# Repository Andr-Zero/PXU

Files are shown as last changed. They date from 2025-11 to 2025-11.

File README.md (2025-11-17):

# PXU - Replacement Power Supply for the Orignial Xbox!

## 🛑 VERY IMPORTANT SAFETY DISCLAIMER 🛑
This project involves working with and replacing a power supply unit that was originally designed to handle mains voltage. The original OEM power supply can retain a lethal electrical charge long after it has been unplugged. Proceed with extreme caution.

 **HIGH VOLTAGE RISK**: You are solely responsible for your safety. Improper handling of electronics can lead to serious injury, death, or fire. If you are not experienced and confident in working with electronics, do not attempt to install this hardware.

**USE AT YOUR OWN RISK**: This is a hobbyist project provided "as is" without warranties of any kind. The author, Andr0, is not responsible for any damage to your console, other property, or any personal injury that may occur from the use or misuse of this hardware.
___
## Features
-   ✨Support 1.0 through 1.6 revisions consoles! ✨  
    *1.0/1.1 requires the proper 12-pin connector.  
    *Switching between 1.0-1.4 and 1.6s requires changing several zero ohm resistors, documented on bottom of the PCB.
-   Accepts any DC input from 16-20V, 100W+ (Including 100W USB-C PD chargers).
-   Features user-replaceable input modules.
-   Designed as a direct swap with the OEM power supply, using the same mounting points.

## Installation
**Warning:** The OEM power supply can be dangerous even after being unplugged for long periods. Proceed with caution!

1.  **Make sure the AC power cord is unplugged from the wall!** Then, press the Xbox's power button a few times to help discharge any residual power.
2.  Open the console and remove the hard drive tray.
3.  Unplug the cable connecting the OEM power supply to the mainboard.
4.  Remove the two screws holding the power supply down. Slide it toward the front of the console just enough to disengage it from the shell's retaining clips.
5.  The power supply should now lift out. You may need to angle it to get it out of the shell.
6.  Installation is the reverse of this process.

## FAQ
**Will my "******"  work as a power source?** I cannot test every power source available. I have personally tested an MSI laptop charger (180W) and an Anker 100W USB-C charger. Similar adapters that meet the specification of 16-20V and can deliver 100W or more should work.

**Can you add feature "X"?** The goal of the main PXU board is to be a drop-in replacement that powers the console just like the OEM supply. Additional features can and should be added as daughterboards using the provided mount points.

**I dont see the USB-C Board Here.** That's in another repo: https://github.com/Andr-Zero/PXU-C-PIM

## License

This project is open-source hardware, licensed under the **CERN-OHL-S v2** (CERN Open Hardware Licence - Strongly Reciprocal).

**Copyright © 2025 Andr0**

You are free to:

-   **Use and reproduce** this design for any purpose.
-   **Modify** the design to fit your needs.  
-   **Distribute** the original design or your modifications.

In return, you must:

-   **Give credit**
-   **Share your changes** under the same CERN-OHL-S v2 license.
-  **Keep all copyright and license notices intact.** As a condition of the license's attribution requirement, all original markings on the PCB silkscreen must be retained. This includes the copyright notice, the PXU and Team Resurgent logos, and any project URLs present in the original design files. These should not be removed or altered.

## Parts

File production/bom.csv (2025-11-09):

Designator | Footprint | Quantity | Value | LCSC Part #
_6, _5, _4, _3, _2, |  | 6
12V, 5V, GND | TestPoint_THTPad_D4.0mm_Drill2.0mm | 3 | TestPoint
C1, C11, C17, C44 | 0603 | 4 | 1uF 16V
C10 | 0805 | 1 | 220nF 25V
C12, C33, C34, C35, C41, C42, C65 | 0603 | 7 | 100nF 10V
C13 | 0603 | 1 | 12pF 25V
C14, C45, C46, C47, C55 | 0805 | 5 | 22uF 25V
C15, C28, C31, C32, C5, C59, C64 | 0603 | 7 | 100nF 50V
C16, C18, C2, C20, C3, C6, C9 | 1210 | 7 | 47uF 25V
C19, C4 | 0603 | 2 | 4.7uF 25V
C21, C22, C36, C38, C40, C48, C69, C7, C70 | 0603 | 9 | 1uF 10V
C23 | CP_Radial_D10.0mm_P5.00mm | 1 | 1500uF 6.3V
C24 | 0603 | 1 | 1uF 35V
C25 | 0603 | 1 | 2.2uF 6.3V
C26, C43, C49, C50, C51, C52, C53, C54, C67, C68 | 1206 | 10 | 100uF 10V
C27, C8 | CP_Radial_D10.0mm_P5.00mm | 2 | 2200uF 16V
C29 | 0603 | 1 | 1nF 50V
C30 | 0603 | 1 | 180pF
C37, C63 | 0805 | 2 | 10uF 10V
C39 | 0603 | 1 | 100pF
C56 | 0603 | 1 | 1uF 6.3V
C57, C58 | 1210 | 2 | 22uF 35V
C60, C61 | 1206 | 2 | 100nF 50V
C62 | CP_Radial_D10.0mm_P5.00mm | 1 | 680uF 35V
C66 | 0603 | 1 | 10uF 16V
IC1 | SON50P500X600X150-23N-D | 1 | TPS53319DQPT
IC2 | SON50P500X600X150-23N-D | 1 | TPS53318DQPT
J1 | Molex_Mini-Fit_Jr_5566-20A_2x10_P4.20mm_Vertical | 1 | 39-38-1203
J2 | CONN_171826-4_TYCO_TYC | 1 | 171826-4
L1 | L_10.4x10.4_H4.8 | 1 | XAL1010-222MED
L2 | L_6.3x6.3_H3 | 1 | XAL6060-103MEB
L3 | L_6.3x6.3_H3 | 1 | XAL6060-472MEC
R1 | 0603 | 1 | 150kΩ
R10 | 1206 | 1 | 0Ω
R11, R2, R26, R32, R33, R4, R6 | 0603 | 7 | 0Ω
R12, R13, R14, R16, R20, R3, R7 | 0603 | 7 | 105kΩ
R15 | 0603 | 1 | 9.53kΩ
R17, R23 | 1206 | 2 | 1MΩ
R18 | 0603 | 1 | 80.6kΩ
R19, R5 | 0603 | 2 | 475kΩ
R21, R8 | 0603 | 2 | 10kΩ
R22 | 0603 | 1 | 44.2kΩ
R24 | 0603 | 1 | 105k Ω
R25 | 0603 | 1 | 33 Ω
R27 | 1206 | 1 | 3Ω
R28 | 0805 | 1 | 1.87kΩ
R29 | 0805 | 1 | 3Ω
R31 | 0603 | 1 | 55kΩ
R34 | 0603 | 1 | 22Ω
R37 | 0603 | 1 | 100Ω
R9 | 0603 | 1 | 71.5kΩ
U1 | D14 | 1 | SN74LVC08ADR
U2 | Texas_HSOP-8-1EP_3.9x4.9mm_P1.27mm_ThermalVias | 1 | LMR33640ADDAR
U3 | CSD25402Q3A | 1 | CSD25402Q3A
U4 | SO-8EP_DIO | 1 | AP7375Q-33SP-13
U5 | SOT-23-5 | 1 | UCC27517A
U6 | SOT-23-6_Handsoldering | 1 | SN74LVC2G17DBVR

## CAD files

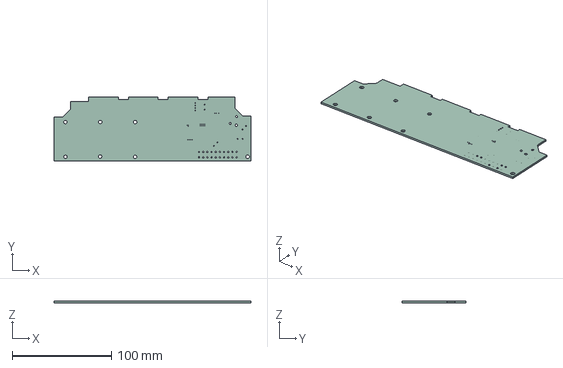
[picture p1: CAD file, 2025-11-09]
KiCad/PXU.step
198.0 x 64.5 x 1.51 mm

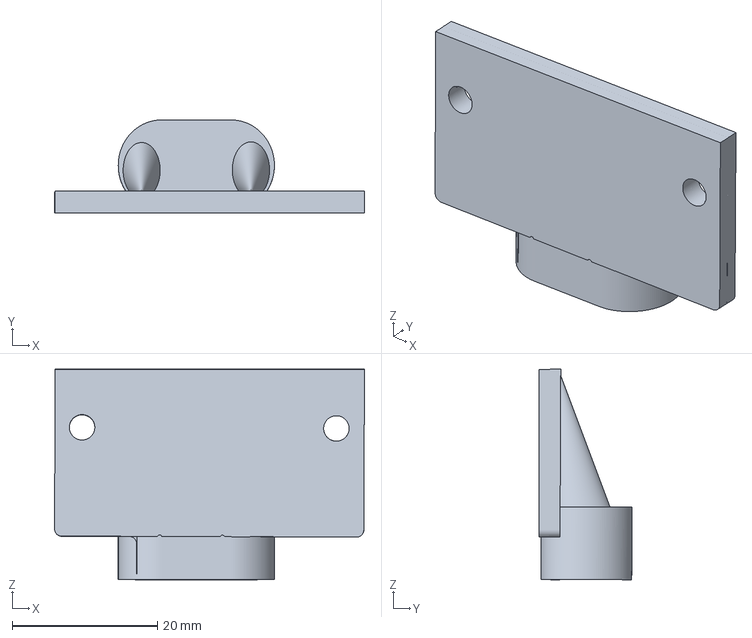
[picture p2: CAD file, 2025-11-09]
PXU Plug Blank.3mf
42.7 x 12.8 x 29.0 mm

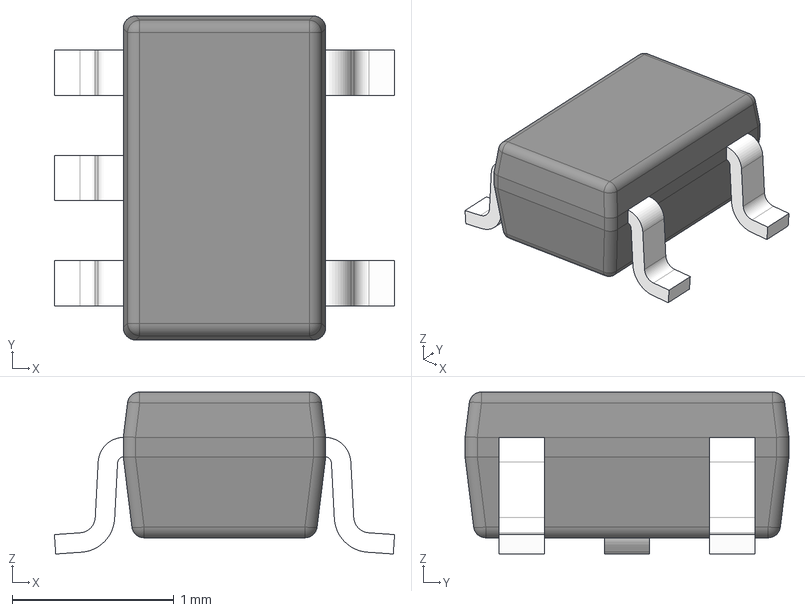
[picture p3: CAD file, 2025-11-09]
KiCad/Imports/DCK0005A.stp
2.10 x 2.00 x 1.00 mm
BODY-SOT
LEAD-SOT x 5
PIN1-ID

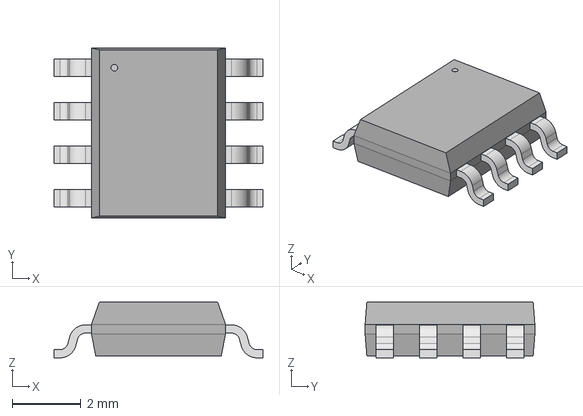
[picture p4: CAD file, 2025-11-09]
KiCad/Imports/SO-8EP_DIO.step
6.10 x 4.95 x 1.63 mm

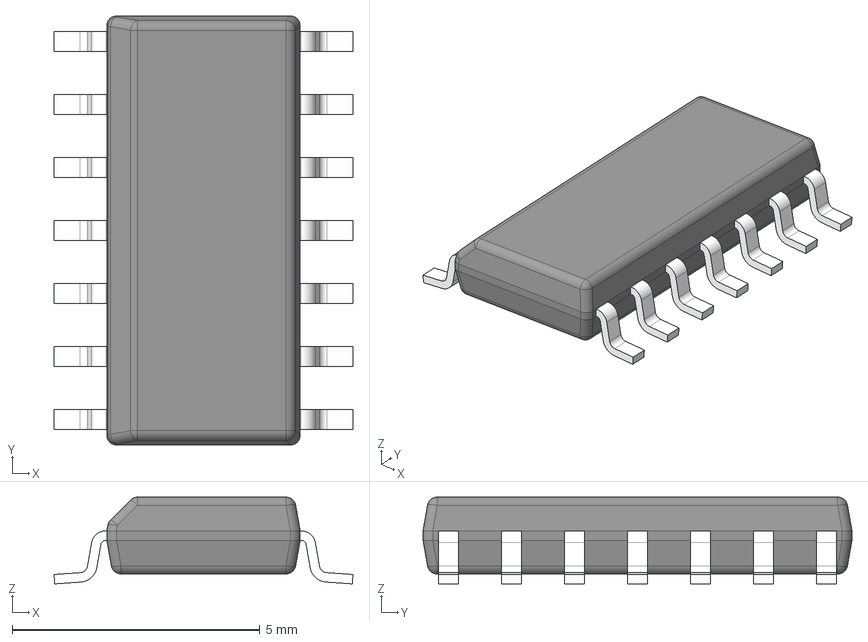
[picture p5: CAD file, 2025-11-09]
KiCad/Imports/D0014A.stp
6.03 x 8.65 x 1.75 mm
BODY-SO
LEAD-SO x 14
PIN1-ID

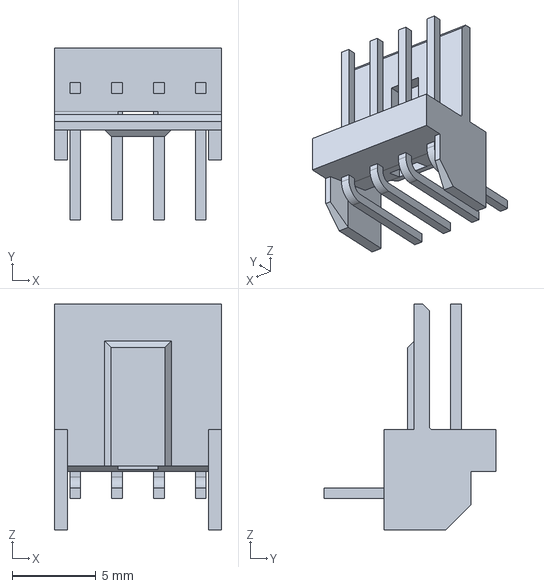
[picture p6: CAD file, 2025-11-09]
KiCad/Imports/CONN_171826-4.stp
10.0 x 10.3 x 13.5 mm

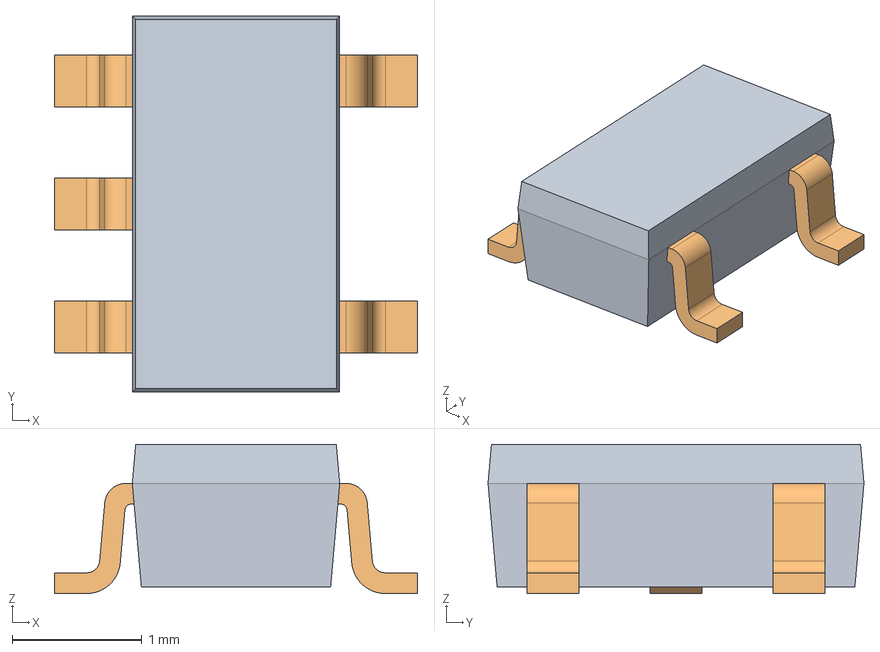
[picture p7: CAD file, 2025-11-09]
KiCad/Imports/SMV_z90.stp
2.80 x 2.90 x 1.15 mm

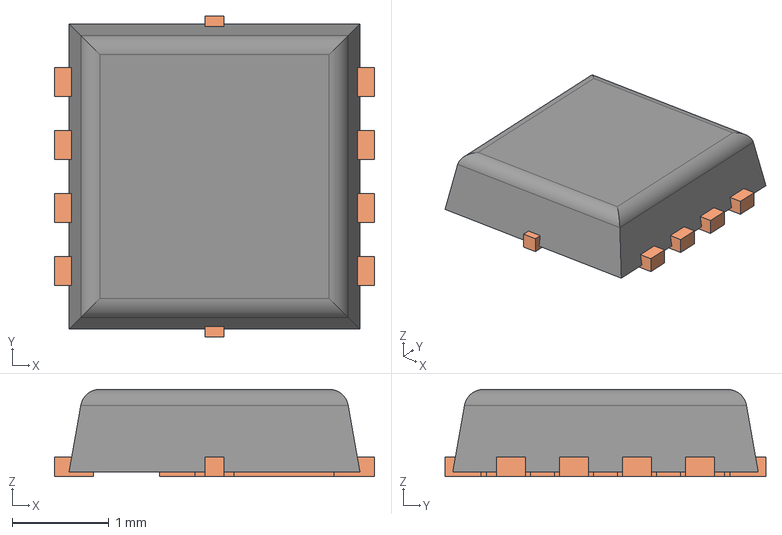
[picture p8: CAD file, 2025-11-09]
KiCad/Imports/CSD25402Q3A.stp
3.30 x 3.31 x 0.9 mm
FRAME

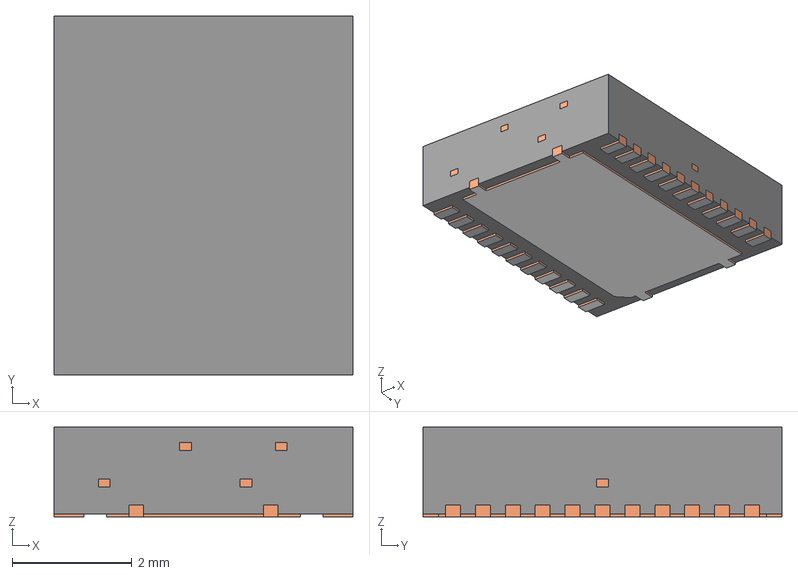
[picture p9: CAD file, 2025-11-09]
KiCad/Imports/TPS53319DQPT.stp
5.00 x 6.00 x 1.50 mm
BODY-SON
FRAME-DQP0022A
PIN1-ID
CLIP1-LSON
CLIP2-LSON

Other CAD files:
KiCad/Imports/DCK0006A.stp
KiCad/Imports/SO-8EP_DIO.stl

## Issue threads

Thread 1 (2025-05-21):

Open Source

harrypm, 2025-05-21:
Hello your project is getting some SEO score attention with prototypes in the wild, so I figured I would come in here and say this is neat, I've got an Xbox I'm going to be refitting soon so good timing I hope.

What I'd like to mention is if you're actually making something for the open source community, please start from the ground up as open source so you're design revisioning can be peer reviewed by fellow engineers, If not improved upon with orientations for cost-effectiveness and long endurance designs.

Would be nice to know if there's some sort of timeline here, because it is awkward making these sort of pokes.

Overall love this project hope this gets mass adoption in the modding community.

eimparas, 2025-05-25:
came here from the MatKC [video](https://www.youtube.com/watch?v=xhCOKw-ICsg) and i thought that i could look at the desing since it peaked my interest

Andr-Zero, 2025-08-08:
Thanks for the interest! I will be publishing everything and releasing the source for everything once I feel the project is ready or as complete as I can make it.

harrypm, 2025-08-08:
> Thanks for the interest! I will be publishing everything and releasing the source for everything once I feel the project is ready or as complete as I can make it.

That means this issue is still valid and standing, that's not how issue tickets work on GitHub.

Andr-Zero, 2025-08-09:
From my understanding of how issues work on github, it's really up to the owner on how they work.

I am going to reopen, and pin,  to serve as a FAQ and allow open dialog.

In regards to peer review. I do agree that to a degree. For me to really understand HOW things work, I still need to tinker and learn. I REALLY hope to have something released soon-ish. I have one specific issue I'm working on, once I have that done and test boards done. I REALLY hope that's it. It's the last thing on my list. After that it's go time! :)

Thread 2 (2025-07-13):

Bas intermittent boot looping 1.0

splitbarrel2, 2025-07-13:
I’m on a 1.0v console and have already ran all 5 jumpers for the trace rot on the power button circuits and recapped all cpu and power related caps. My issue is that many times turning the console on it will try to boot but the moment the fans and HDD get power it turns off (no lights on the front). Unplugging the console from the wall sometimes helps other times it does not. Sometimes unplugging the type c charger from the wall fixes it but not always. Lately it’s been getting really bad. I frequently open my console up and take out the motherboard. This last time I noticed some strain on the top two white and blue wires that are for the power data transfer back to the pxu. They almost looked severed so I cut them past the strain point and resoldered. That seemed to help for a little bit but didn’t fix it either. I really like having the usbc charging but I’m about at my wits end trying to figure out why I have to play with it like this someone please tell me what I’m doing wrong or if those wires are just prone to internal breaking and should be replaced with thicker gage I’m so lost.

Andr-Zero, 2025-07-13:
1.0s have a noticeable inrush compared the later revisions, finding very few adapters are not particular happy with them. For example, the Anker adapter I've been using does not like to reboot the console after running for more than 15 minutes. What AC adapter are you using? Do you have another adapter to test with? Just only to verify that is not problem. Also when it fails to boot, does the LEDs on the USB board change?

The length of the Blue\White cables indeed should be longer. The next order of supplies will about 3-4cm longer, maybe more. likely to do the same with the two black and orange wire, not sure yet. Have not heard anyone say anything about them breaking internally.

splitbarrel2, 2025-07-14:
Thank you so much for your quick reply! I've spent the last day making absolutely sure that it was not something to do with the wiring for the trace rot or any other weird wiring and doing some trouble shooting! The adapter that I am using is a "j5create 108W USB-C Super Charger". It states that it can due 100w over the type-c (20v 5a) so long as nothing else is also plugged into it. I don't have another AC adapter at the moment capable of the 100w but I will order another one ASAP and update you when I get it to see if it is just that. When it fails to boot the green light in the middle (Labeled D2) stays on and does not blink or change color.

I'd like to clarify its not exactly boot looping. To be more specific pressing the power button causes the fans to spin for less than 1 second, the HDD to make a noise, the controller lights to flash and then it kills itself. Sometimes when it fails it fails HARD barely spins a fan at all and the flash for the controller would be very fast. Other times it would spin them much harder almost a full second or so. The controller would even light up for second too. Like it was about to power on but just couldn't. Holding the power button causes the system to repeat the fail until unpressed however it did launch during the fail cycle a couple of times. Pressing / Holding the eject button gives the same thing. It seems like the longer i use the adapter the more it likes to act up. Towards the first 5 minutes or so it works very well the failure rate is super low but the more time plugged in the more likely it is to fail booting. After about 20 minutes of being plugged in I'm lucky if i can get it turned back on at all. The only thing that works without unplugging something is waiting with the console powered off for 30-60 seconds then pressing the power button.

Also I've been noticing that I've been getting some screen flashing while playing games that I do not get with the OEM power supply. It's oddly intermittent sometimes it happens 10 times in a minute and sometimes once in 2 or 3 minutes and nothing in particular seems to cause it or make it worse. The screen flashing sometimes appears as distortion to the image that lasts for no more than a frame or two and other times it's a total black flash lasting for the same amount of time. I've tried to press a button at the same time of the flashing to confirm its not just a visual effect and it does not appear to take the command if pressed at ruffly the same time as a flash.

As for the blue and white wires it would be nice to have them a bit longer but I just wanted to make sure that the stress spot I put on them by accidently forcing the HDD tray down on the wires wasn't causing a break or bad connection.

splitbarrel2, 2025-07-14:
I was able to obtain another usb-c charger. An anker 140w, 4-port, PD 3.1 its even got a small screen on it to show which port is using how much wattage. I've been playing with it for a little bit now and it appears to do the same thing with about the same frequency. If this is due to the inrushing issues would it be possible to easily add an inrush current limiter to any part of the circuit without designing a new pcb just to see if it would be more stable?

Andr-Zero, 2025-07-14:
Before you order another AC adapter, the one you have *SHOULD* work just fine. Lets see if we can do some basic testing. Do you have a voltmeter? Are you willing to measure some voltages for me if you do?

I called it boot looping for lack of a better term, perhaps short cycling? What you're describing is indicative of the PwrGood signal not getting asserted properly.  Voltage rails must come to within 10% of it's target within the soft-start time, then this signal tells the console to start running. If it does not receive that signal within a set timeframe from letting go of the front buttons, the console stops trying to turn on.

Seen a couple reasons why this happens, most common issues I've found so far are; a short circuit, loose connection somewhere, unstable input, and failing\incorrect capacitors in the console. The "Sometimes works, sometimes doesn't" you describe does lead me to believe that it's something to do with the input side. The unplugging of the AC adapter reinforces this thought. If that is the AC adapter or the USB-C board, that is the question.

The screen flickering is a new one. That I would have to look into more.

I'm going to cut myself off here since I see you added another update as I was typing. Having tried another adapter, I'm wanting to swap the pxu and see if the problem continues. Can you contact me on my shop with the order number? I feel this is the best way to get to the quickest resolution.

Andr-Zero, 2025-08-08:
Just to close this up for anyone else following along. I ended exchanging the unit. The 3.3v LDO failed, swapping it caused it to work properly again.

Closed 2025-08-08.

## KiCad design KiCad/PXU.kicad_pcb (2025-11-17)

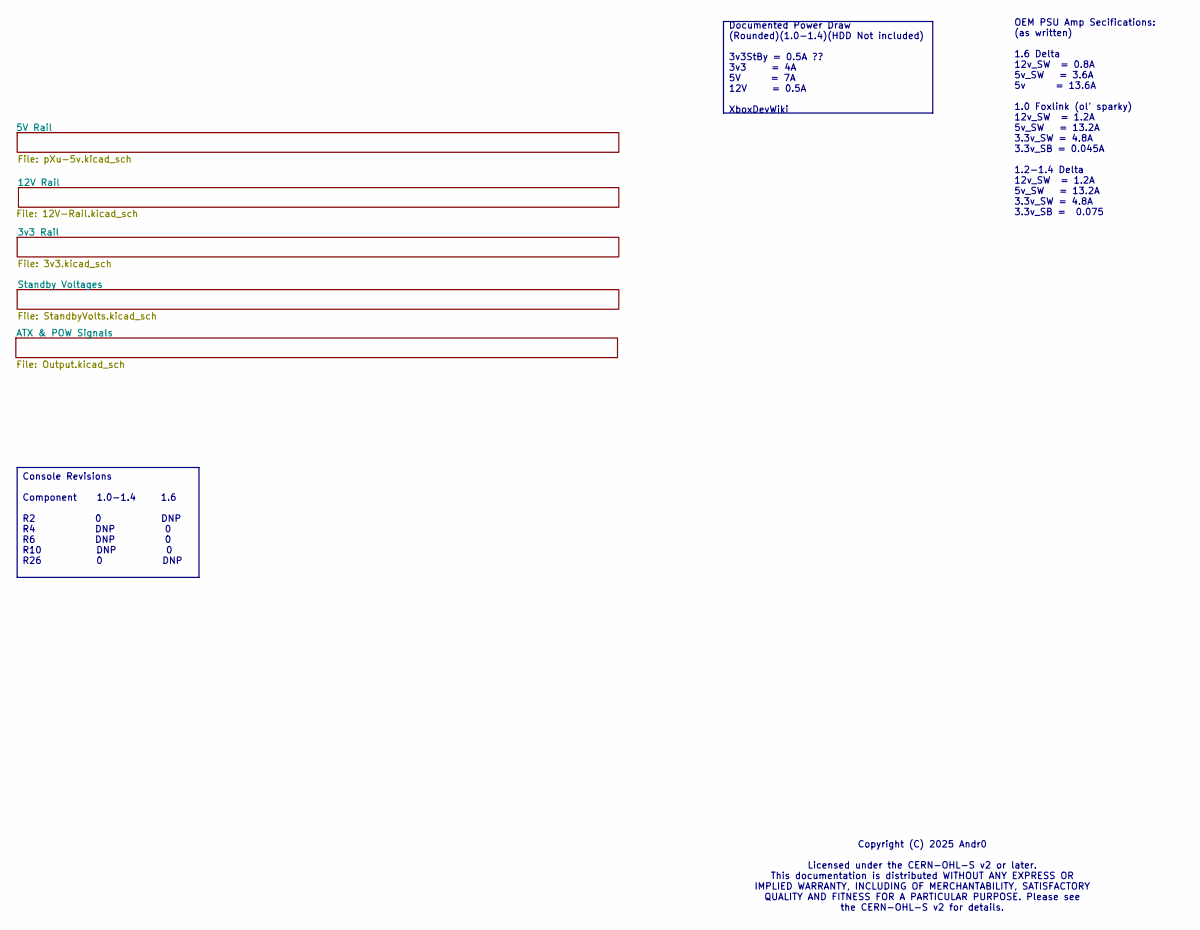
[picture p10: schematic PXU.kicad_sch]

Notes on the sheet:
OEM PSU Amp Secifications: (as written) 1.6 Delta 12v_SW = 0.8A 5v_SW = 3.6A 5v = 13.6A 1.0 Foxlink (ol' sparky) 12v_SW = 1.2A 5v_SW = 13.2A 3.3v_SW = 4.8A 3.3v_SB = 0.045A 1.2-1.4 Delta 12v_SW = 1.2A 5v_SW = 13.2A 3.3v_SW = 4.8A 3.3v_SB = 0.075
Copyright (C) 2025 Andr0 Licensed under the CERN-OHL-S v2 or later. This documentation is distributed WITHOUT ANY EXPRESS OR IMPLIED WARRANTY, INCLUDING OF MERCHANTABILITY, SATISFACTORY QUALITY AND FITNESS FOR A PARTICULAR PURPOSE. Please see the CERN-OHL-S v2 for details.
Console Revisions Component 1.0-1.4 1.6 R2 0 DNP R4 DNP 0 R6 DNP 0 R10 DNP 0 R26 0 DNP
Documented Power Draw (Rounded)(1.0-1.4)(HDD Not included) 3v3StBy = 0.5A ?? 3v3 = 4A 5V = 7A 12V = 0.5A XboxDevWiki

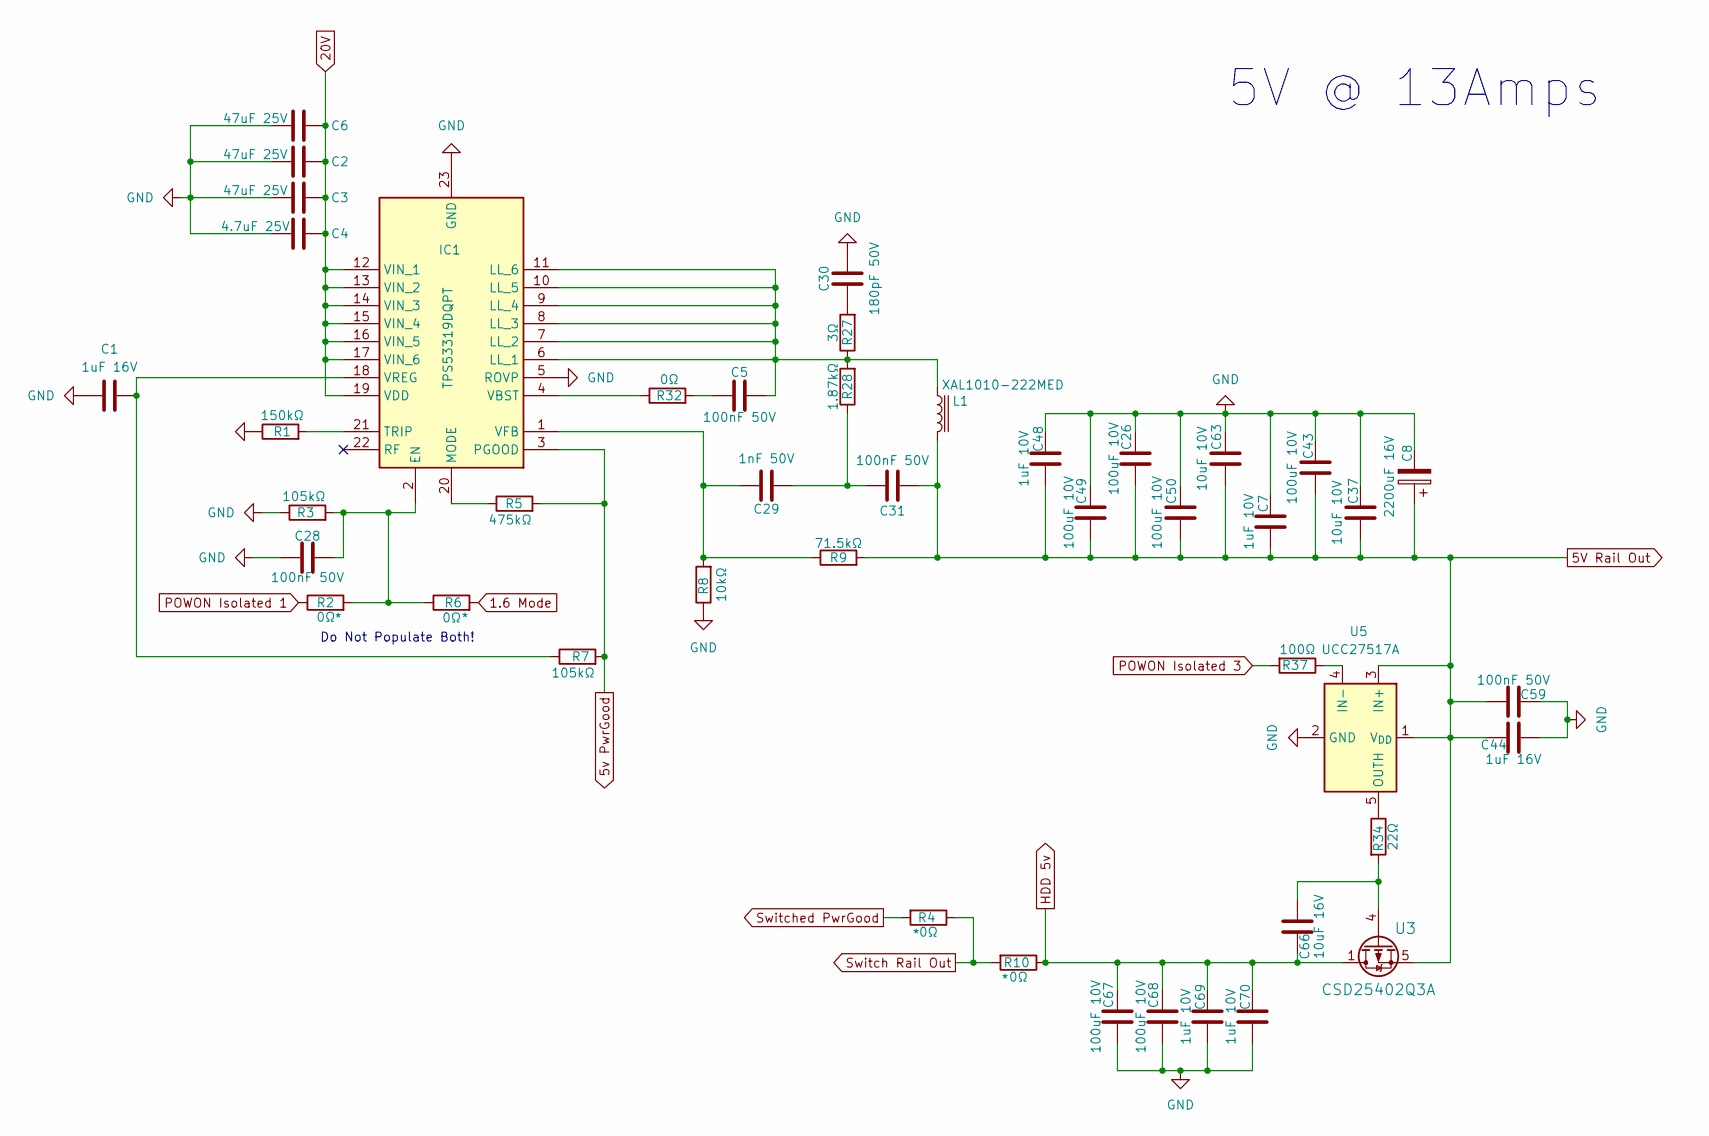
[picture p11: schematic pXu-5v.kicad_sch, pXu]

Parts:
C1, C44: 1uF 16V; C_0603_1608Metric_Pad1.08x0.95mm_HandSolder
C2, C3, C6: 47uF 25V; C_1210_3225Metric_Pad1.33x2.70mm_HandSolder
C4: 4.7uF 25V; C_0603_1608Metric_Pad1.08x0.95mm_HandSolder
C5, C28, C31, C59: 100nF 50V; C_0603_1608Metric_Pad1.08x0.95mm_HandSolder
C7, C48, C69, C70: 1uF 10V; C_0603_1608Metric_Pad1.08x0.95mm_HandSolder
C8: 2200uF 16V; CP_Radial_D10.0mm_P5.00mm
C26, C43, C49, C50, C67, C68: 100uF 10V; C_1206_3216Metric_Pad1.33x1.80mm_HandSolder
C29: 1nF 50V; C_0603_1608Metric_Pad1.08x0.95mm_HandSolder
C30: 180pF 50V; C_0603_1608Metric_Pad1.08x0.95mm_HandSolder
C37, C63: 10uF 10V; C_0805_2012Metric_Pad1.18x1.45mm_HandSolder
C66: 10uF 16V; C_0603_1608Metric_Pad1.08x0.95mm_HandSolder
IC1: TPS53319DQPT; SON50P500X600X150-23N-D; Mouser Part Number 595-TPS53319DQPT
L1: XAL1010-222MED; L_10.4x10.4_H4.8; Part# XAL1010-222MED
R1: 150kΩ; R_0603_1608Metric_Pad0.98x0.95mm_HandSolder
R2, R4, R6, R32: 0Ω; R_0603_1608Metric_Pad0.98x0.95mm_HandSolder
R3, R7: 105kΩ; R_0603_1608Metric_Pad0.98x0.95mm_HandSolder
R5: 475kΩ; R_0603_1608Metric_Pad0.98x0.95mm_HandSolder
R8: 10kΩ; R_0603_1608Metric_Pad0.98x0.95mm_HandSolder
R9: 71.5kΩ; R_0603_1608Metric_Pad0.98x0.95mm_HandSolder
R10: 0Ω; R_1206_3216Metric_Pad1.30x1.75mm_HandSolder
R27: 3Ω; R_1206_3216Metric_Pad1.30x1.75mm_HandSolder
R28: 1.87kΩ; R_0805_2012Metric_Pad1.20x1.40mm_HandSolder
R34: 22Ω; R_0603_1608Metric_Pad0.98x0.95mm_HandSolder
R37: 100Ω; R_0603_1608Metric_Pad0.98x0.95mm_HandSolder
U3: CSD25402Q3A; VSON-8_3.3x3.3mm_P0.65mm_NexFET
U5: UCC27517A; SOT-23-5

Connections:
1.6 Mode: R6.2; also elsewhere on the board
5V Rail Out: C7.2, C8.1, C26.2, C31.1, C37.2, C43.2, C44.1, C48.2, C49.2, C50.2, C59.2, C63.2, L1.2, R9.2, U3.5 (S), U5.1 (V_{DD}), U5.3 (IN+); also elsewhere on the board
5v PwrGood: IC1.3 (PGOOD), R5.2, R7.2; also elsewhere on the board
20V: C2.2, C3.2, C4.2, C6.2, IC1.12 (VIN_1), IC1.13 (VIN_2), IC1.14 (VIN_3), IC1.15 (VIN_4), IC1.16 (VIN_5), IC1.17 (VIN_6), IC1.19 (VDD); also elsewhere on the board
GND: C1.1, C2.1, C3.1, C4.1, C6.1, C7.1, C8.2, C26.1, C28.1, C30.2, C37.1, C43.1, C44.2, C48.1, C49.1, C50.1, C59.1, C63.1, C67.2, C68.2, C69.2, C70.2, IC1.5 (ROVP), IC1.23 (GND), R1.1, R3.1, R8.1, U5.2 (GND); also elsewhere on the board
HDD 5v: C66.1, C67.1, C68.1, C69.1, C70.1, R10.1, U3.1 (D), U3.2 (D), U3.3 (D); also elsewhere on the board
unnamed: C5.2, R32.2
unnamed: C29.1, C31.2, R28.1
unnamed: C30.1, R27.2
unnamed: C28.2, IC1.2 (EN), R2.2, R3.2, R6.1
unnamed: C5.1, IC1.6 (LL_1), IC1.7 (LL_2), IC1.8 (LL_3), IC1.9 (LL_4), IC1.10 (LL_5), IC1.11 (LL_6), L1.1, R27.1, R28.2
unnamed: IC1.20 (MODE), R5.1
unnamed: IC1.21 (TRIP), R1.2
unnamed: IC1.4 (VBST), R32.1
unnamed: C29.2, IC1.1 (VFB), R8.2, R9.1
unnamed: C1.2, IC1.18 (VREG), R7.1
unnamed: C66.2, R34.2, U3.4 (G)
unnamed: R37.1, U5.4 (IN-)
unnamed: R34.1, U5.5 (OUTH)
POWON Isolated 1: R2.1; also elsewhere on the board
POWON Isolated 3: R37.2; also elsewhere on the board
Switch Rail Out: R4.1, R10.2; also elsewhere on the board
Switched PwrGood: R4.2; also elsewhere on the board

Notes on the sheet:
Do Not Populate Both!
5V @ 13Amps

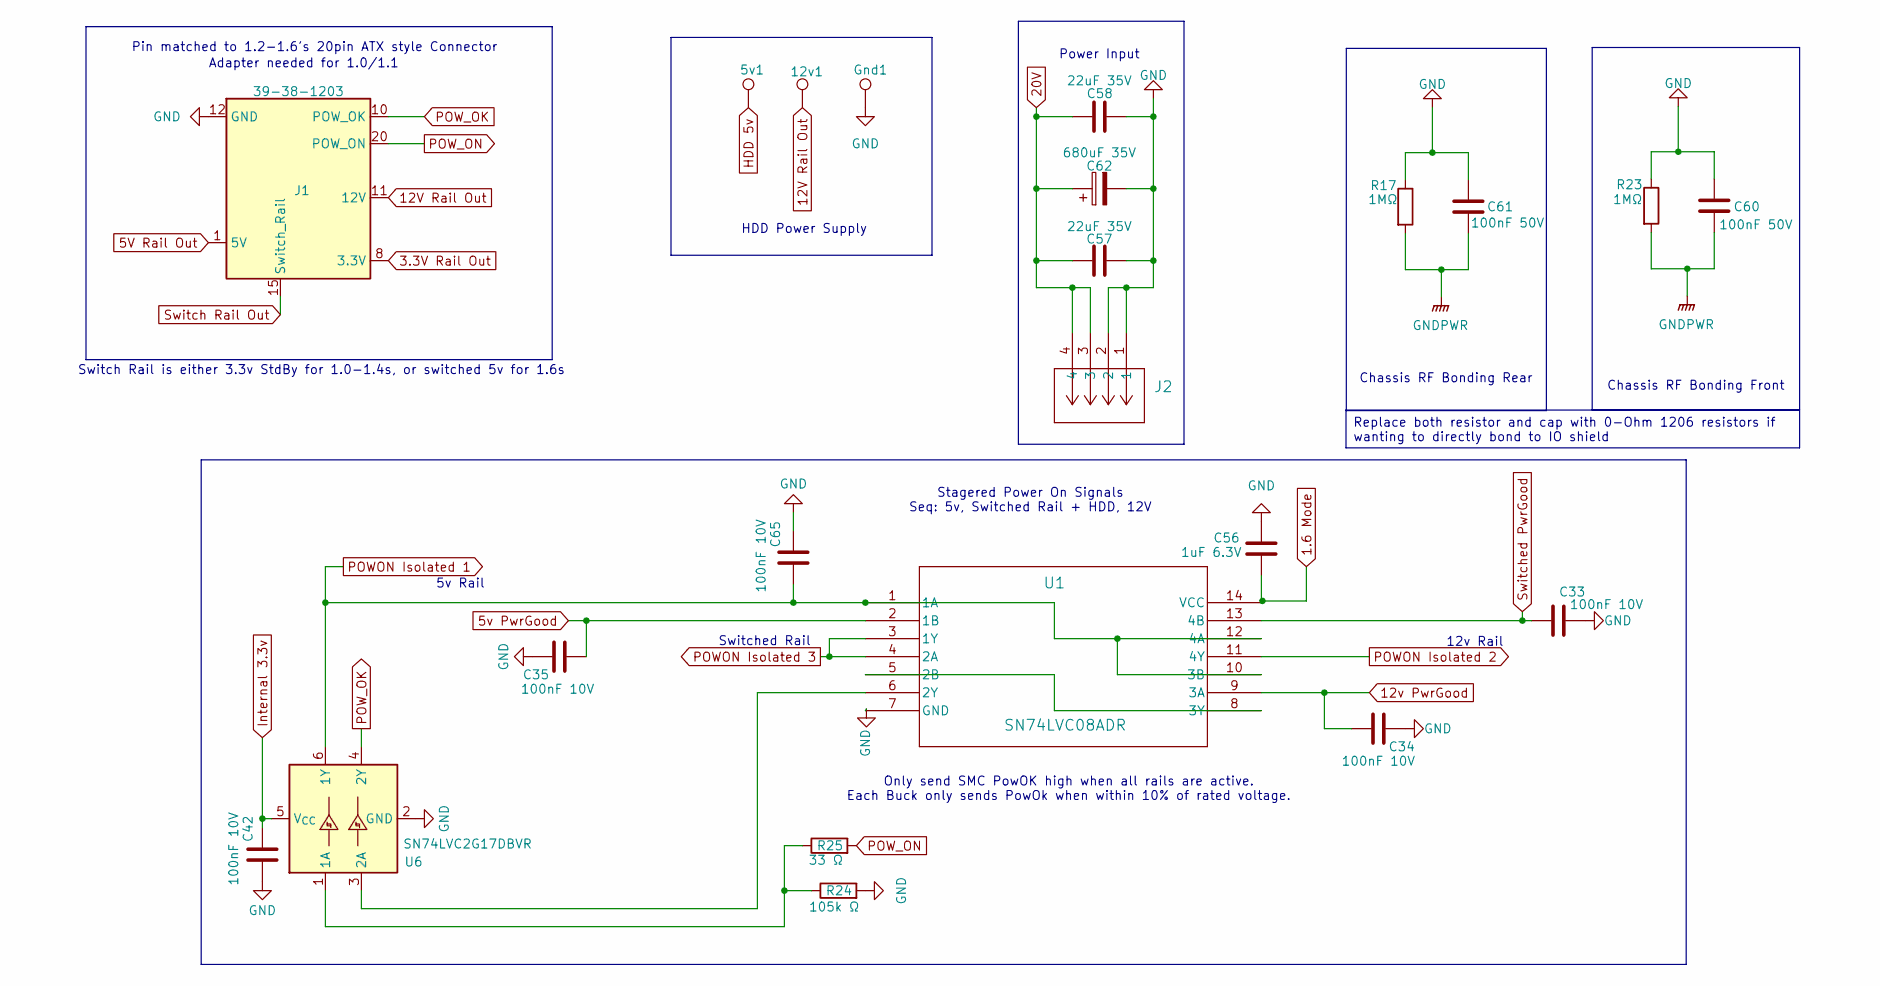
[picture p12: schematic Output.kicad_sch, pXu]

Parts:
5v1, 12v1: TestPoint; TestPoint_THTPad_D4.0mm_Drill2.0mm
C33, C34, C35, C42, C65: 100nF 10V; C_0603_1608Metric_Pad1.08x0.95mm_HandSolder
C56: 1uF 6.3V; C_0603_1608Metric_Pad1.08x0.95mm_HandSolder
C57, C58: 22uF 35V; C_1210_3225Metric_Pad1.33x2.70mm_HandSolder
C60, C61: 100nF 50V; C_1206_3216Metric_Pad1.33x1.80mm_HandSolder
C62: 680uF 35V; CP_Radial_D10.0mm_P5.00mm
Gnd1: TestPoint; TestPoint_THTPad_D4.0mm_Drill2.0mm
J1: 39-38-1203; Molex_Mini-Fit_Jr_5566-20A_2x10_P4.20mm_Vertical
J2: 171826-4; CONN_171826-4_TYCO_TYC
R17, R23: 1MΩ; R_1206_3216Metric_Pad1.30x1.75mm_HandSolder
R24: 105k Ω; R_0603_1608Metric_Pad0.98x0.95mm_HandSolder
R25: 33 Ω; R_0603_1608Metric_Pad0.98x0.95mm_HandSolder
U1: SN74LVC08ADR; D14
U6: SN74LVC2G17DBVR; SOT-23-6_Handsoldering

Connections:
1.6 Mode: C42.2, C56.2, U1.14 (VCC), U6.5 (V_{CC}); also elsewhere on the board
3.3V Rail Out: J1.7 (3.3V), J1.8 (3.3V), J1.17 (3.3V), J1.18 (3.3V); also elsewhere on the board
5V Rail Out: J1.1 (5V), J1.2 (5V), J1.3 (5V), J1.13 (5V); also elsewhere on the board
5v PwrGood: C35.2, U1.2 (1B); also elsewhere on the board
12V Rail Out: 12v1.1, J1.11 (12V); also elsewhere on the board
12v PwrGood: C34.1, U1.9 (3A); also elsewhere on the board
20V: C57.1, C58.1, C62.1, J2.3, J2.4; also elsewhere on the board
GND: C33.1, C34.2, C35.1, C42.1, C56.1, C57.2, C58.2, C60.1, C61.1, C62.2, C65.1, Gnd1.1, J1.4 (GND), J1.5 (GND), J1.6 (GND), J1.9 (GND), J1.12 (GND), J1.14 (GND), J1.16 (GND), J1.19 (GND), J2.1, J2.2, R17.1, R23.1, R24.2, U1.7 (GND), U6.2 (GND); also elsewhere on the board
GNDPWR: C60.2, C61.2, R17.2, R23.2
unnamed: U1.5 (2B), U1.8 (3Y)
unnamed: U1.6 (2Y), U6.3 (2A)
unnamed: R24.1, R25.1, U6.1 (1A)
POWON Isolated 1: C65.2, U1.1 (1A), U1.10 (3B), U1.12 (4A), U6.6 (1Y); also elsewhere on the board
POWON Isolated 2: U1.11 (4Y); also elsewhere on the board
POWON Isolated 3: U1.3 (1Y), U1.4 (2A); also elsewhere on the board
POW_OK: J1.10 (POW_OK), U6.4 (2Y)
POW_ON: J1.20 (POW_ON), R25.2
Switch Rail Out: J1.15 (Switch_Rail); also elsewhere on the board
Switched PwrGood: C33.2, U1.13 (4B); also elsewhere on the board

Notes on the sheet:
HDD Power Supply
Switched Rail
Chassis RF Bonding Rear
Adapter needed for 1.0/1.1
Pin matched to 1.2-1.6's 20pin ATX style Connector
Stagered Power On Signals Seq: 5v, Switched Rail + HDD, 12V
12v Rail
Only send SMC PowOK high when all rails are active. Each Buck only sends PowOk when within 10% of rated voltage.
Power Input
Chassis RF Bonding Front
5v Rail
Switch Rail is either 3.3v StdBy for 1.0-1.4s, or switched 5v for 1.6s
Replace both resistor and cap with 0-Ohm 1206 resistors if wanting to directly bond to IO shield

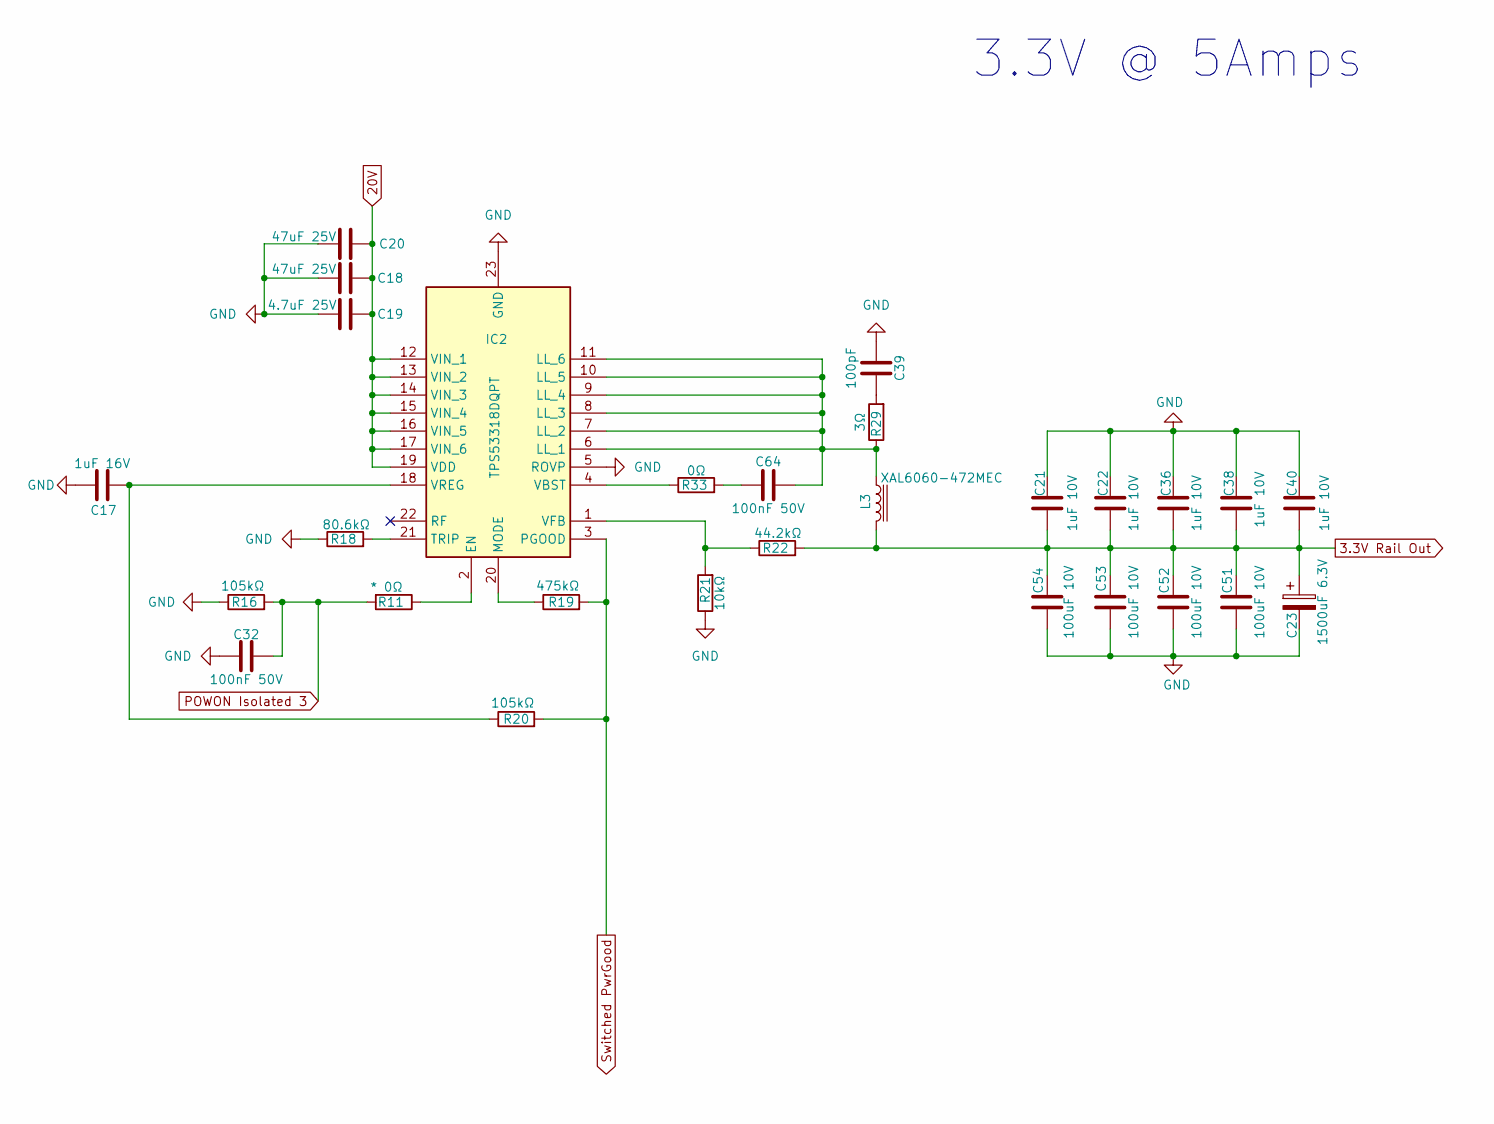
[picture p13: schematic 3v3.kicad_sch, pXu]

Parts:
C17: 1uF 16V; C_0603_1608Metric_Pad1.08x0.95mm_HandSolder
C18, C20: 47uF 25V; C_1210_3225Metric_Pad1.33x2.70mm_HandSolder
C19: 4.7uF 25V; C_0603_1608Metric_Pad1.08x0.95mm_HandSolder
C21, C22, C36, C38, C40: 1uF 10V; C_0603_1608Metric_Pad1.08x0.95mm_HandSolder
C23: 1500uF 6.3V; CP_Radial_D10.0mm_P5.00mm
C32, C64: 100nF 50V; C_0603_1608Metric_Pad1.08x0.95mm_HandSolder
C39: 100pF; C_0603_1608Metric_Pad1.08x0.95mm_HandSolder; Voltage 50V
C51, C52, C53, C54: 100uF 10V; C_1206_3216Metric_Pad1.33x1.80mm_HandSolder
IC2: TPS53318DQPT; SON50P500X600X150-23N-D; Mouser Part Number 595-TPS53319DQPT
L3: XAL6060-472MEC; L_6.3x6.3_H3; Part# XAL6060-472MEC
R11, R33: 0Ω; R_0603_1608Metric_Pad0.98x0.95mm_HandSolder
R16, R20: 105kΩ; R_0603_1608Metric_Pad0.98x0.95mm_HandSolder
R18: 80.6kΩ; R_0603_1608Metric_Pad0.98x0.95mm_HandSolder
R19: 475kΩ; R_0603_1608Metric_Pad0.98x0.95mm_HandSolder
R21: 10kΩ; R_0603_1608Metric_Pad0.98x0.95mm_HandSolder
R22: 44.2kΩ; R_0603_1608Metric_Pad0.98x0.95mm_HandSolder
R29: 3Ω; R_0805_2012Metric_Pad1.20x1.40mm_HandSolder

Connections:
3.3V Rail Out: C21.2, C22.2, C23.1, C36.2, C38.2, C40.2, C51.1, C52.1, C53.1, C54.1, L3.2, R22.2; also elsewhere on the board
20V: C18.2, C19.2, C20.2, IC2.12 (VIN_1), IC2.13 (VIN_2), IC2.14 (VIN_3), IC2.15 (VIN_4), IC2.16 (VIN_5), IC2.17 (VIN_6), IC2.19 (VDD); also elsewhere on the board
GND: C17.1, C18.1, C19.1, C20.1, C21.1, C22.1, C23.2, C32.1, C36.1, C38.1, C39.1, C40.1, C51.2, C52.2, C53.2, C54.2, IC2.5 (ROVP), IC2.23 (GND), R16.1, R18.1, R21.1; also elsewhere on the board
unnamed: C39.2, R29.2
unnamed: C64.2, R33.2
unnamed: IC2.2 (EN), R11.1
unnamed: C64.1, IC2.6 (LL_1), IC2.7 (LL_2), IC2.8 (LL_3), IC2.9 (LL_4), IC2.10 (LL_5), IC2.11 (LL_6), L3.1, R29.1
unnamed: IC2.20 (MODE), R19.1
unnamed: IC2.21 (TRIP), R18.2
unnamed: IC2.4 (VBST), R33.1
unnamed: IC2.1 (VFB), R21.2, R22.1
unnamed: C17.2, IC2.18 (VREG), R20.1
POWON Isolated 3: C32.2, R11.2, R16.2; also elsewhere on the board
Switched PwrGood: IC2.3 (PGOOD), R19.2, R20.2; also elsewhere on the board

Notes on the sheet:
3.3V @ 5Amps

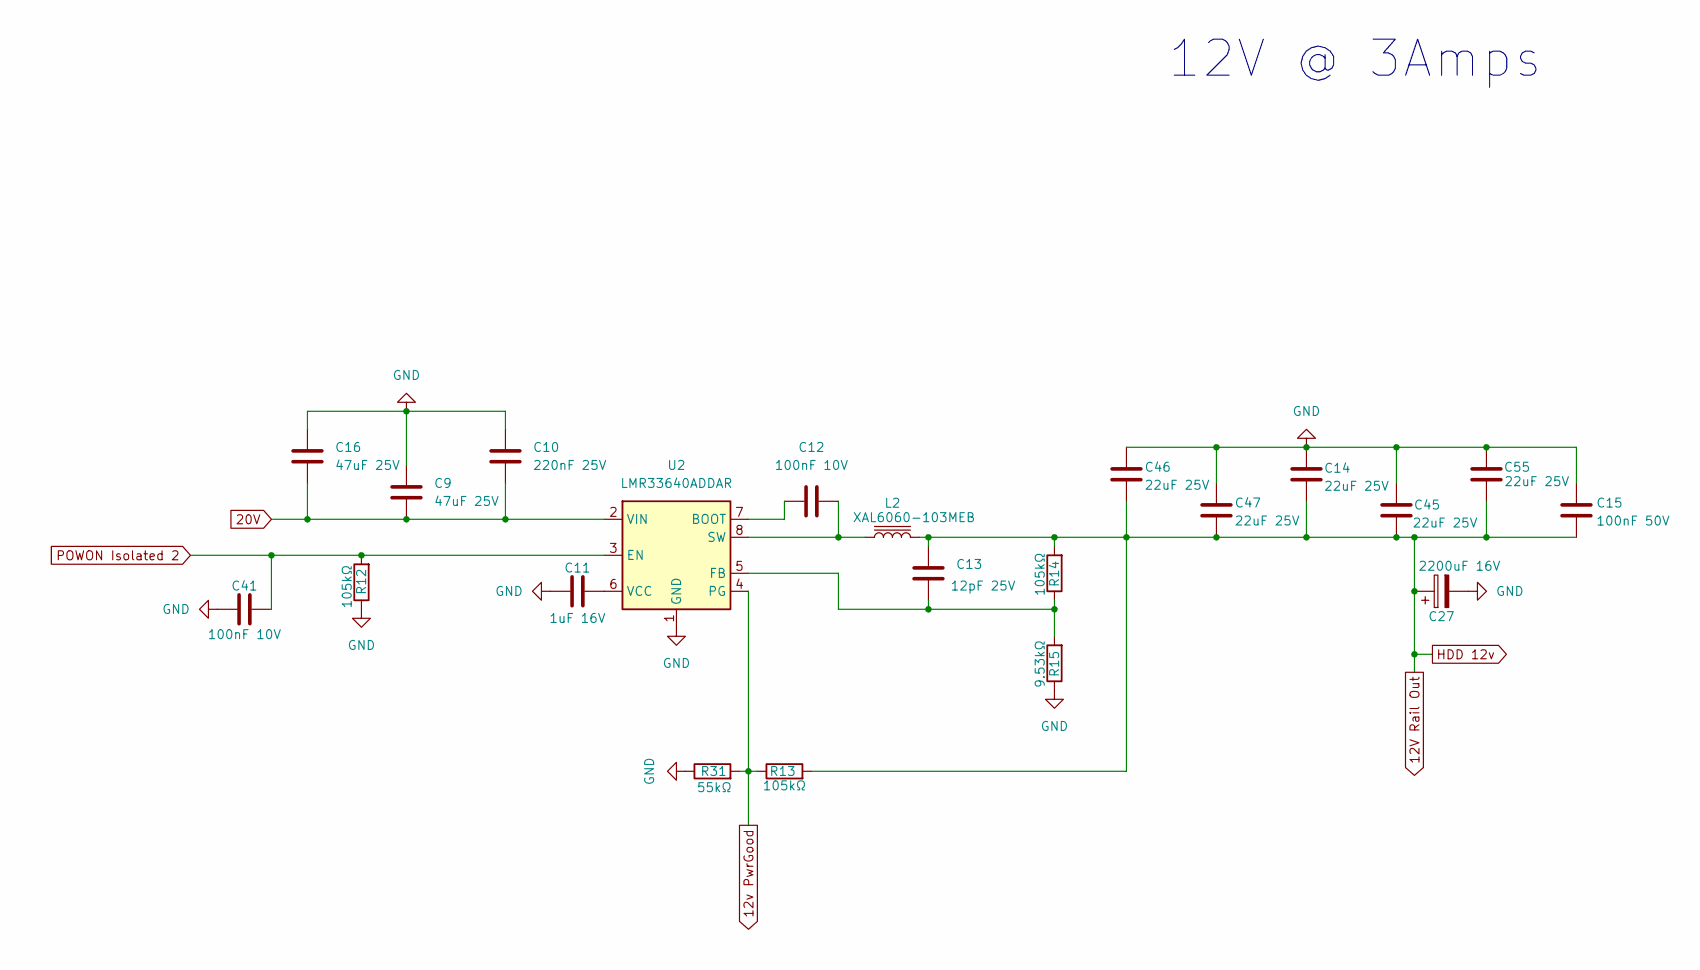
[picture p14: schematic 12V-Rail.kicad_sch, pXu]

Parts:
C9, C16: 47uF 25V; C_1210_3225Metric_Pad1.33x2.70mm_HandSolder
C10: 220nF 25V; C_0805_2012Metric_Pad1.18x1.45mm_HandSolder
C11: 1uF 16V; C_0603_1608Metric_Pad1.08x0.95mm_HandSolder
C12, C41: 100nF 10V; C_0603_1608Metric_Pad1.08x0.95mm_HandSolder
C13: 12pF 25V; C_0603_1608Metric_Pad1.08x0.95mm_HandSolder
C14, C45, C46, C47, C55: 22uF 25V; C_0805_2012Metric_Pad1.18x1.45mm_HandSolder
C15: 100nF 50V; C_0603_1608Metric_Pad1.08x0.95mm_HandSolder
C27: 2200uF 16V; CP_Radial_D10.0mm_P5.00mm
L2: XAL6060-103MEB; L_6.3x6.3_H3; Part# XAL6060-682MEB
R12, R13, R14: 105kΩ; R_0603_1608Metric_Pad0.98x0.95mm_HandSolder
R15: 9.53kΩ; R_0603_1608Metric_Pad0.98x0.95mm_HandSolder
R31: 55kΩ; R_0603_1608Metric_Pad0.98x0.95mm_HandSolder
U2: LMR33640ADDAR; Texas_HSOP-8-1EP_3.9x4.9mm_P1.27mm_ThermalVias

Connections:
12V Rail Out: C13.2, C14.2, C15.1, C27.1, C45.2, C46.2, C47.2, C55.1, L2.2, R13.2, R14.2; also elsewhere on the board
12v PwrGood: R13.1, R31.2, U2.4 (PG); also elsewhere on the board
20V: C9.2, C10.2, C16.2, U2.2 (VIN); also elsewhere on the board
GND: C9.1, C10.1, C11.1, C14.1, C15.2, C16.1, C27.2, C41.1, C45.1, C46.1, C47.1, C55.2, R12.1, R15.1, R31.1, U2.1 (GND), U2.9 (GND); also elsewhere on the board
unnamed: C12.1, U2.7 (BOOT)
unnamed: C13.1, R14.1, R15.2, U2.5 (FB)
unnamed: C12.2, L2.1, U2.8 (SW)
unnamed: C11.2, U2.6 (VCC)
POWON Isolated 2: C41.2, R12.2, U2.3 (EN); also elsewhere on the board

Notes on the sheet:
12V @ 3Amps

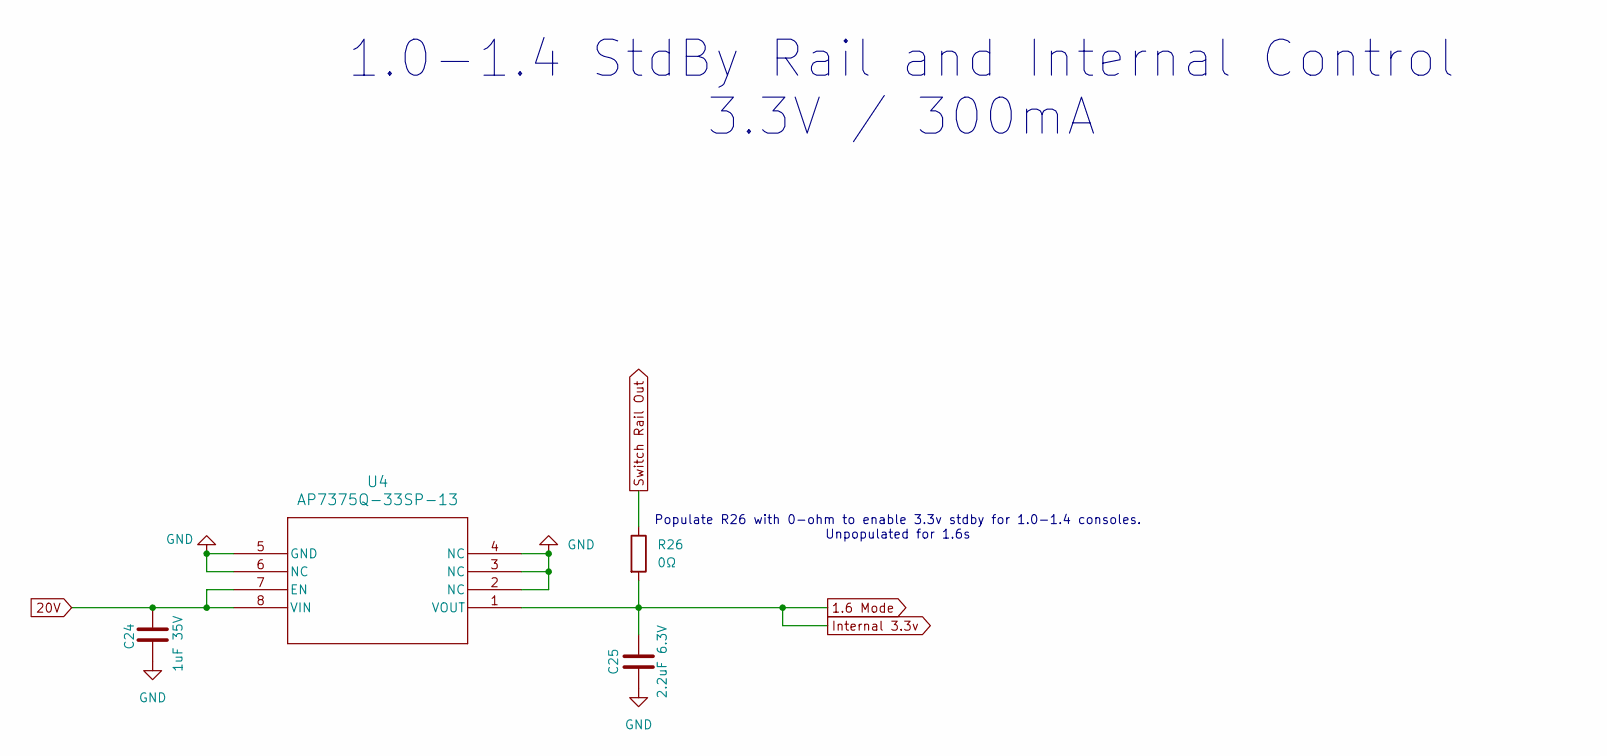
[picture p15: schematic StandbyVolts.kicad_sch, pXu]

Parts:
C24: 1uF 35V; C_0603_1608Metric_Pad1.08x0.95mm_HandSolder
C25: 2.2uF 6.3V; C_0603_1608Metric_Pad1.08x0.95mm_HandSolder
R26: 0Ω; R_0603_1608Metric_Pad0.98x0.95mm_HandSolder
U4: AP7375Q-33SP-13; SO-8EP_DIO

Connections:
1.6 Mode: C25.1, R26.2, U4.1 (VOUT); also elsewhere on the board
20V: C24.1, U4.7 (EN), U4.8 (VIN); also elsewhere on the board
GND: C24.2, C25.2, U4.2 (NC), U4.3 (NC), U4.4 (NC), U4.5 (GND), U4.6 (NC); also elsewhere on the board
Switch Rail Out: R26.1; also elsewhere on the board

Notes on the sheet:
Populate R26 with 0-ohm to enable 3.3v stdby for 1.0-1.4 consoles. Unpopulated for 1.6s
1.0-1.4 StdBy Rail and Internal Control 3.3V / 300mA

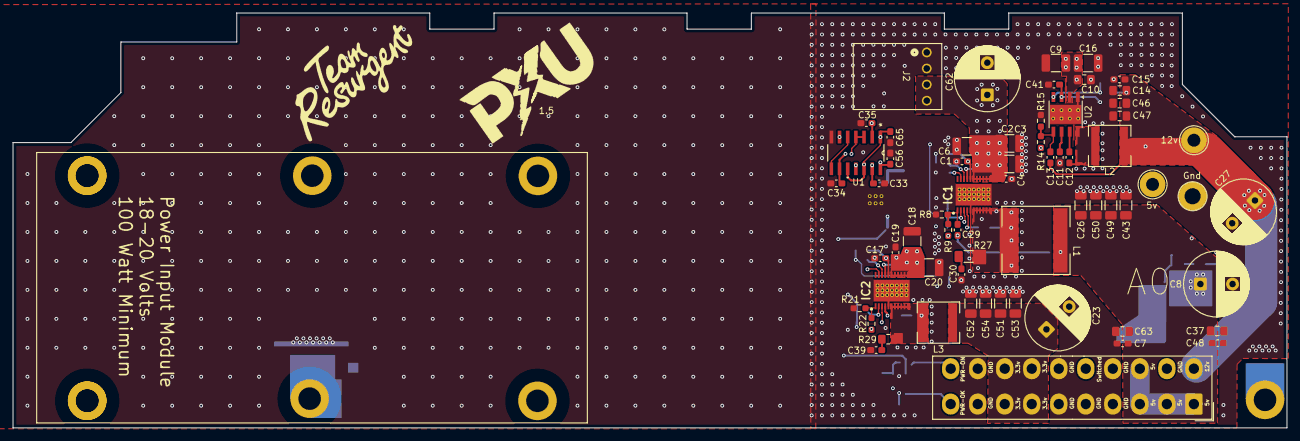
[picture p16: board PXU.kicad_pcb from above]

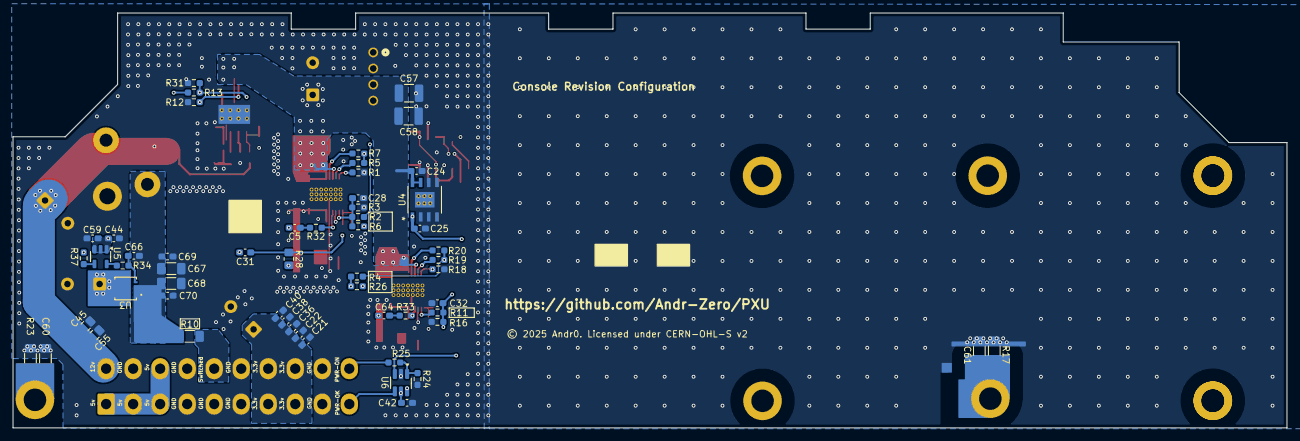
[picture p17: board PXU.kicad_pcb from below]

Board: 4 copper layers, 198.0 x 64.5 mm, 120 parts (56 on the bottom side), 46 nets.

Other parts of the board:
5v, 12v: TestPoint; TestPoint_THTPad_D4.0mm_Drill2.0mm
Gnd: TestPoint; TestPoint_THTPad_D4.0mm_Drill2.0mm

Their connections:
12V Rail Out: 12v.1; also elsewhere on the board
GND: Gnd.1; also elsewhere on the board
HDD 5v: 5v.1; also elsewhere on the board

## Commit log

2025-11-09 Initial Upload
    [12V-Rail.kicad_sch, 3v3.kicad_sch, 3v3StdBy.kicad_sch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]
2025-11-17 License upload
    Missed including license in initial upload
    [PXU.kicad_pcb, PXU.kicad_sch]

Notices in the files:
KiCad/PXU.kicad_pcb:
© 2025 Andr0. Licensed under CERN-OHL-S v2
